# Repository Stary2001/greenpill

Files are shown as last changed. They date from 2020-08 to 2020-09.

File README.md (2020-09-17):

Greenpill
===
*Breadboard-able SAMD51 development board*

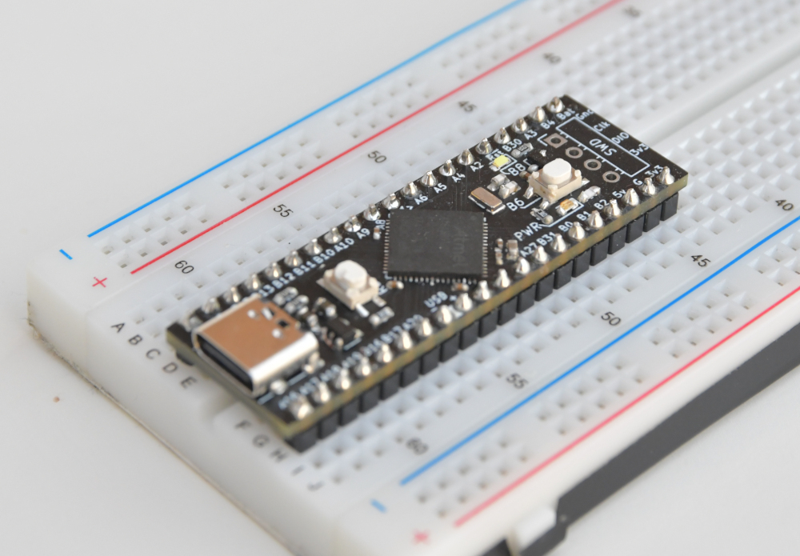
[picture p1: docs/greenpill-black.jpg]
Assembled PCB in a breadboard


Inspired by the popular low-cost "Bluepill" and "Blackpill" STM32 boards, Greenpill aims to maintain some compatibility with those designs while adding features from the SAMD5x platform. Greenpill is designed to be used with [CircuitPython], although a SAMD51 port of Arduino could also be used.

## Features
 - SAMD51J20A-M microcontroller
   - Arm Cortex-M4 @ 120 MHz
   - 8 USB endpoints &ndash; enough for CDC & MSC (for CircuitPython), and some extras (eg. AUDIO)
 - Reversible USB Type-C connector supporting USB 2.0 data rates
 - On-board user LED and button
 - External 32.768 kHz crystal oscillator for RTC + clock source.
 - Up to 13 PWM-capable pins usable **simultaneously**
 - SPI flash footprint on underside - no pin conflicts with broken out pins (uses **SERCOM2**).

Greenpill Schematic

## Flashing CircuitPython
1. **TODO: add UF2 bootloader instructions**
2. [Build CircuitPython][BuildCPy] from [the fork][CPyFork]. Use the `atsamd` port and `BOARD=greenpill`.
3. Enter the UF2 bootloader by double-tapping the RESET button on Greenpill
4. You should now have a removable storage device called `CPYBOOT`. Copy `PATHTOUF2` to the root directory of this device. Once it has finished copying, `CPYBOOT` will disappear and `GREENPILL` will appear. You have now installed CircuitPython.

## Pin assignment
Pins are numbered **counter-clockwise** starting at the top-left pin (to the left of the USB-C connector).

| Greenpill Pin | GPIO name  | Available SERCOMs* | Available PWM timers* | Comment |
|---|---|---|---|---|
| User LED | PB09 | - | TC4/WO[1] | |
| User Button | PB06 | - | - | Externally pulled up to 3v3 |
| VBat sense | PB03 | - | - | Connected to VBat via diode D3 |
| 1 | PA16 | SERCOM1/PAD[0]<br>SERCOM3/PAD[1] | TCC1/WO[0]<br>TCC0/WO[4] | |
| 2 | PA17 | SERCOM1/PAD[1]<br>SERCOM3/PAD[0] | TC2/WO[1]<br>TCC1/WO[1]<br>TCC0/WO[5] | |
| 3 | PA18 | SERCOM1/PAD[2]<br>SERCOM3/PAD[2] | TCC1/WO[2]<br>TCC0/WO[6] | |
| 4 | PA19 | SERCOM1/PAD[3]<br>SERCOM3/PAD[3] | TC3/WO[1]<br>TCC1/WO[3]<br>TCC0/WO[7] | |
| 5 | PB16 | SERCOM5/PAD[0] | TCC3/WO[0]<br>TCC0/WO[4] | |
| 6 | PB01 | SERCOM5/PAD[3] | TC7/WO[1] | |
| 7 | PB00 | SERCOM5/PAD[2] | - | |
| 8 | PA24 | | | USB D- |
| 9 | PA25 | | | USB D+ |
| 10 | PA20 | SERCOM5/PAD[2]<br>SERCOM3/PAD[2] | TCC1/WO[4]<br>TCC0/WO[0] - | |
| 11 | PB22 | SERCOM1/PAD[2]<br>SERCOM5/PAD[2] | | |
| 12 | PB23 | SERCOM1/PAD[3]<br>SERCOM5/PAD[3] | TC7/WO[1] | |
| 13 | PA27 | - | - | |
| 14 | PB31 | SERCOM5/PAD[0] | TC0/WO[1]<br>TCC4/WO[1]<br>TCC0/WO[7] | |
| 15 | PA22 | SERCOM3/PAD[0]<br>SERCOM5/PAD[1] | TCC1/WO[6]<br>TCC0/WO[2] | |
| 16 | PB17 | SERCOM5/PAD[1] | TC6/WO[1]<br>TCC3/WO[1]<br>TCC0/WO[5] | |
| 17 | PB02 | SERCOM5/PAD[0] | TCC2/WO[2] | |
| 18 | **5V** | | | |
| 19 | **Ground** | | | |
| 20 | **3.3V** | | | |
| 21 | VBat | | | |
| 22 | PB04 | - | - | |
| 23 | PA03 | - | - | |
| 24 | PB30 | SERCOM5/PAD[1] | TCC4/WO[0]<br>TCC0/WO[6] | |
| 25 | ¬Reset | | | |
| 26 | PA02 | - | - | |
| 27 | PA08 | SERCOM4/PAD[0] | - | |
| 28 | PA05 | SERCOM0/PAD[1] | TC0/WO[1] | |
| 29 | PA07 | SERCOM0/PAD[3] | TC1/WO[1] | |
| 30 | PA06 | SERCOM0/PAD[2] | - | |
| 31 | PA04 | SERCOM0/PAD[0] | - | |
| 32 | PA09 | SERCOM0/PAD[1] | TC0/WO[1]<br>TCC0/WO[1]<br>TCC1/WO[5] | |
| 33 | PA10 | SERCOM0/PAD[2] | TCC0/WO[2]<br>TCC1/WO[6] | |
| 34 | PB10 | SERCOM4/PAD[2] | TCC0/WO[4]<br>TCC1/WO[0] | |
| 35 | PB11 | SERCOM4/PAD[3] | TC5/WO[1]<br>TCC0/WO[5]<br>TCC1/WO[1] | |
| 36 | PB12 | SERCOM4/PAD[0] | TCC3/WO[0]<br>TCC0/WO[0] | |
| 37 | PB13 | SERCOM4/PAD[1] | TC4/WO[1]<br>TCC3/WO[1]<br>TCC0/WO[1] | |
| 38 | **3.3V** | | | |
| 39 | **Ground** | | | |
| 40 | **5V** | | | |

\* SERCOM2 and all TC*n*/WO[0] have been removed from this table. SERCOM2 is used by the SPI flash, and TC*n*/WO[0] timers are not usable for PWM output by CircuitPython. For a full reference of pin capability, see Table 6-1 in the [SAM D5x datasheet][samd5xdata]

## License
The contents of this repository, which include the Greenpill hardware, documentation, and design files, are released under the **Solderpad 2.1 license**. The recommended firmware for GreenPill (CircuitPython) is NOT part of this repository. Both [Adafruit/CircuitPython][CircuitPython] and the [fork][CPyFork] that provides Greenpill compatibility are released under the **MIT License** 

[CircuitPython]: https://github.com/Adafruit/CircuitPython "Adafruit/CircuitPython on GitHub"
[CPyFork]: https://github.com/Stary2001/circuitpython/tree/greenpill "Branch 'greenpill' from Stary2001/CircuitPython on GitHub; forked from Adafruit"
[BuildCPy]: https://learn.adafruit.com/building-circuitpython?view=all "Building CircuitPython | Adafruit Learning System"
[samd5xdata]: https://ww1.microchip.com/downloads/en/DeviceDoc/SAM_D5xE5x_Family_Data_Sheet_DS60001507F.pdf "SAM D5x/E5x Family Data Sheet | Microchip (PDF)"

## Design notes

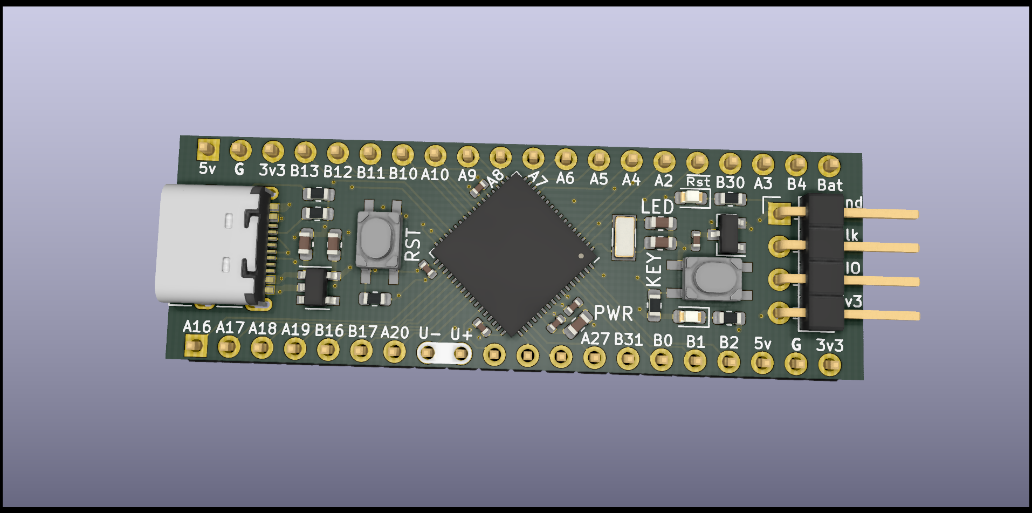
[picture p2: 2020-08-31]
1.0/greenpill.png

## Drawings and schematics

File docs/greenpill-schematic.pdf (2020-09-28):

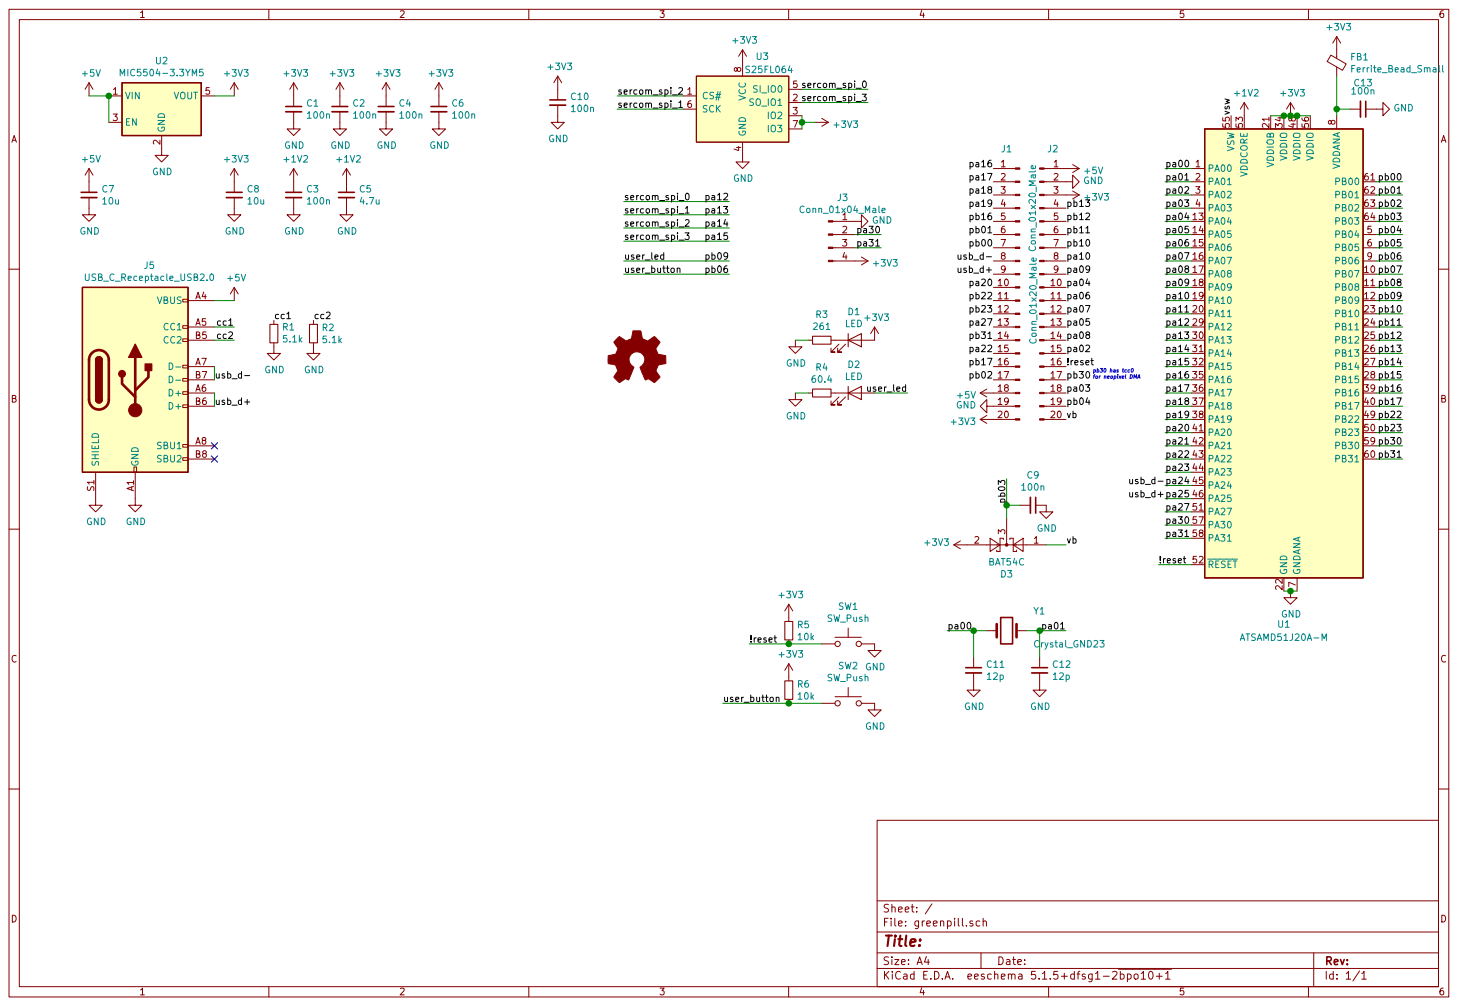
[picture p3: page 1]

File: greenpill.sch Sheet: /
Id: 1/1 Title:

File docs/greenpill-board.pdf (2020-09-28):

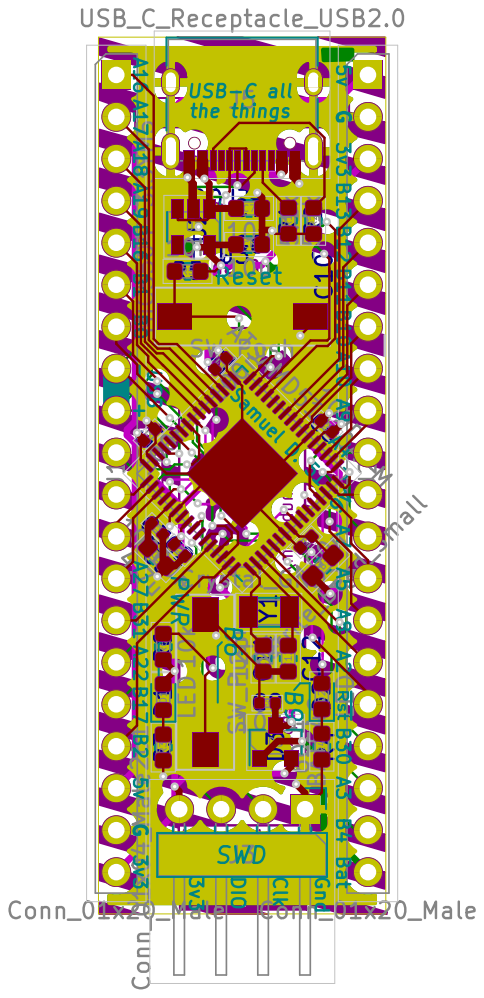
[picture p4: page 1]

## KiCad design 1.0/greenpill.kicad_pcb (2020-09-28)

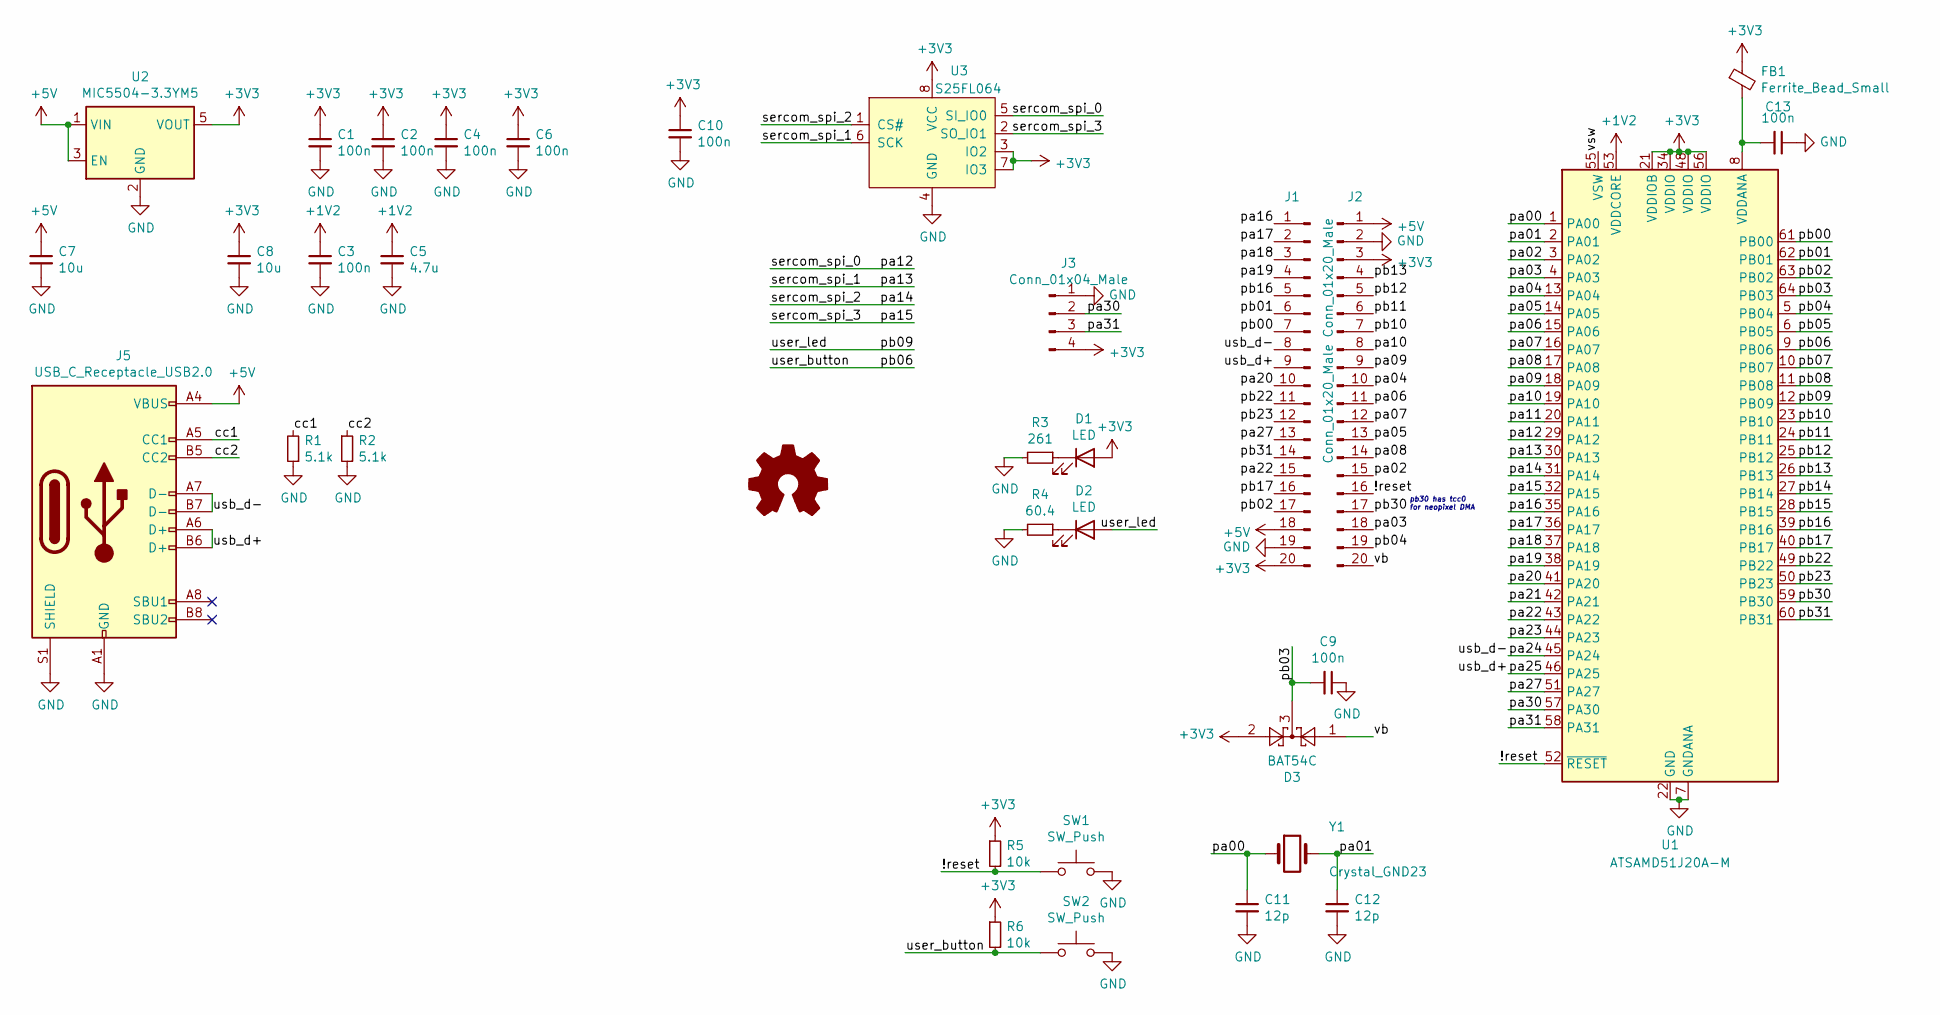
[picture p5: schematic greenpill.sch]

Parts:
C1, C2, C3, C4, C6, C9, C10: 100n; C_0402_1005Metric; MPN GRM155R61A104KA01J
C5: 4.7u; C_0603_1608Metric; MPN CL10A475KQ8NNNC
C7, C8: 10u; C_0603_1608Metric; MPN GRM188R61A106KE69J
C11, C12: 12p; C_0603_1608Metric; MPN C0603C120J5GACTU
C13: 100n; C_0402_1005Metric
D1: LED; LED_0603_1608Metric; MPN 150060RS75000
D2: LED; LED_0603_1608Metric; MPN 150060BS75000
D3: BAT54C; SOT-23; MPN BAT54C,215
FB1: Ferrite_Bead_Small; R_0603_1608Metric_Pad1.05x0.95mm_HandSolder
J1, J2: Conn_01x20_Male; PinHeader_1x20_P2.54mm_Vertical
J3: Conn_01x04_Male; PinHeader_1x04_P2.54mm_Horizontal
J5: USB_C_Receptacle_USB2.0; USB_C_Receptacle_XKB_U262-16XN-4BVC11; MPN lmao aliexpress
LOGO1: Logo_Open_Hardware_Small; OSHW-Symbol_4x4.5mm_SilkScreen
R1, R2: 5.1k; R_0603_1608Metric; MPN RC0603FR-075K1L
R3: 261; R_0603_1608Metric; MPN P261HCT-ND
R4: 60.4; R_0603_1608Metric; MPN RC0603FR-0760R4L
R5, R6: 10k; R_0603_1608Metric; MPN RC0603FR-0710KL
SW1, SW2: SW_Push; PTS636; MPN PTS815 SJM 250 SMTR LFS
U1: ATSAMD51J20A-M; QFN-64-1EP_9x9mm_P0.5mm_EP4.7x4.7mm; MPN ATSAMD51J20A-MU
U2: MIC5504-3.3YM5; SOT-23-5; MPN MIC5504-3.3YM5-TR
U3: S25FL064; SOIC-8_5.23x5.23mm_P1.27mm; MPN S25FL064LABMFN010
Y1: Crystal_GND23; Crystal_SMD_3215-2Pin_3.2x1.5mm; MPN FC-135 32.7680KA-A5

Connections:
+1V2: C3.1, C5.1, U1.53 (VDDCORE)
+3V3: C1.1, C2.1, C4.1, C6.1, C8.1, C10.1, D1.2 (A), D3.2, FB1.1, J1.20, J2.3, J3.4, R5.1, R6.1, U1.21 (VDDIOB), U1.34 (VDDIO), U1.48 (VDDIO), U1.56 (VDDIO), U2.5 (VOUT), U3.3 (IO2), U3.7 (IO3), U3.8 (VCC)
+5V: C7.1, J1.18, J2.1, J5.A4 (VBUS), J5.A9 (VBUS), J5.B4 (VBUS), J5.B9 (VBUS), U2.1 (VIN), U2.3 (EN)
/!reset: J2.16, R5.2, SW1.1, U1.52 (~RESET)
/cc1: J5.A5 (CC1), R1.2
/cc2: J5.B5 (CC2), R2.1
/pa00: C11.1, U1.1 (PA00), Y1.1
/pa01: C12.1, U1.2 (PA01), Y1.2
/pa02: J2.15, U1.3 (PA02)
/pa03: J2.18, U1.4 (PA03)
/pa04: J2.10, U1.13 (PA04)
/pa05: J2.13, U1.14 (PA05)
/pa06: J2.11, U1.15 (PA06)
/pa07: J2.12, U1.16 (PA07)
/pa08: J2.14, U1.17 (PA08)
/pa09: J2.9, U1.18 (PA09)
/pa10: J2.8, U1.19 (PA10)
/pa11: U1.20 (PA11)
/pa12: U1.29 (PA12), U3.5 (SI_IO0)
/pa13: U1.30 (PA13), U3.6 (SCK)
/pa14: U1.31 (PA14), U3.1 (CS#)
/pa15: U1.32 (PA15), U3.2 (SO_IO1)
/pa16: J1.1, U1.35 (PA16)
/pa17: J1.2, U1.36 (PA17)
/pa18: J1.3, U1.37 (PA18)
/pa19: J1.4, U1.38 (PA19)
/pa20: J1.10, U1.41 (PA20)
/pa21: U1.42 (PA21)
/pa22: J1.15, U1.43 (PA22)
/pa23: U1.44 (PA23)
/pa24: J1.8, J5.A7 (D-), J5.B7 (D-), U1.45 (PA24)
/pa25: J1.9, J5.A6 (D+), J5.B6 (D+), U1.46 (PA25)
/pa27: J1.13, U1.51 (PA27)
/pa30: J3.2, U1.57 (PA30)
/pa31: J3.3, U1.58 (PA31)
/pb00: J1.7, U1.61 (PB00)
/pb01: J1.6, U1.62 (PB01)
/pb02: J1.17, U1.63 (PB02)
/pb03: C9.2, D3.3, U1.64 (PB03)
/pb04: J2.19, U1.5 (PB04)
/pb05: U1.6 (PB05)
/pb06: R6.2, SW2.1, U1.9 (PB06)
/pb07: U1.10 (PB07)
/pb08: U1.11 (PB08)
/pb09: D2.2 (A), U1.12 (PB09)
/pb10: J2.7, U1.23 (PB10)
/pb11: J2.6, U1.24 (PB11)
/pb12: J2.5, U1.25 (PB12)
/pb13: J2.4, U1.26 (PB13)
/pb14: U1.27 (PB14)
/pb15: U1.28 (PB15)
/pb16: J1.5, U1.39 (PB16)
/pb17: J1.16, U1.40 (PB17)
/pb22: J1.11, U1.49 (PB22)
/pb23: J1.12, U1.50 (PB23)
/pb30: J2.17, U1.59 (PB30)
/pb31: J1.14, U1.60 (PB31)
/vb: D3.1, J2.20
/vsw: U1.55 (VSW)
GND: C1.2, C2.2, C3.2, C4.2, C5.2, C6.2, C7.2, C8.2, C9.1, C10.2, C11.2, C12.2, C13.1, J1.19, J2.2, J3.1, J5.A1 (GND), J5.A12 (GND), J5.B1 (GND), J5.B12 (GND), J5.S1 (SHIELD), R1.1, R2.2, R3.2, R4.2, SW1.2, SW2.2, U1.7 (GNDANA), U1.22 (GND), U1.33 (GND), U1.47 (GND), U1.54 (GND), U1.65 (GND), U2.2 (GND), U3.4 (GND)
unnamed: C13.2, FB1.2, U1.8 (VDDANA)
unnamed: D1.1 (K), R3.1
unnamed: D2.1 (K), R4.1

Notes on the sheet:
pb30 has tcc0 for neopixel DMA

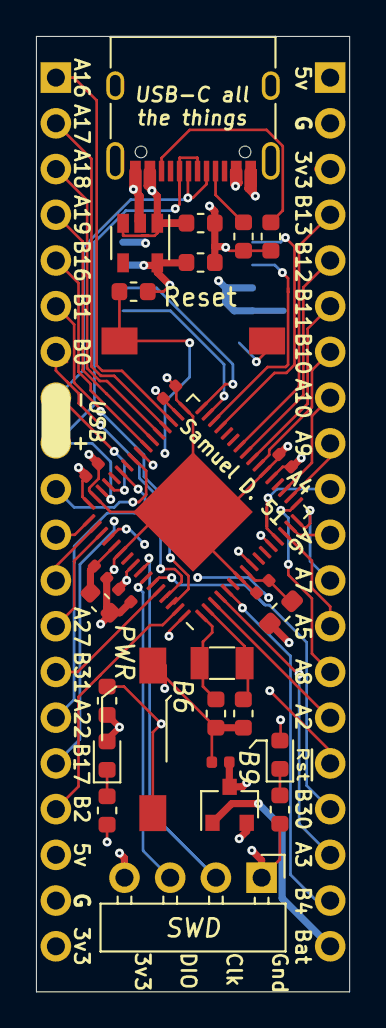
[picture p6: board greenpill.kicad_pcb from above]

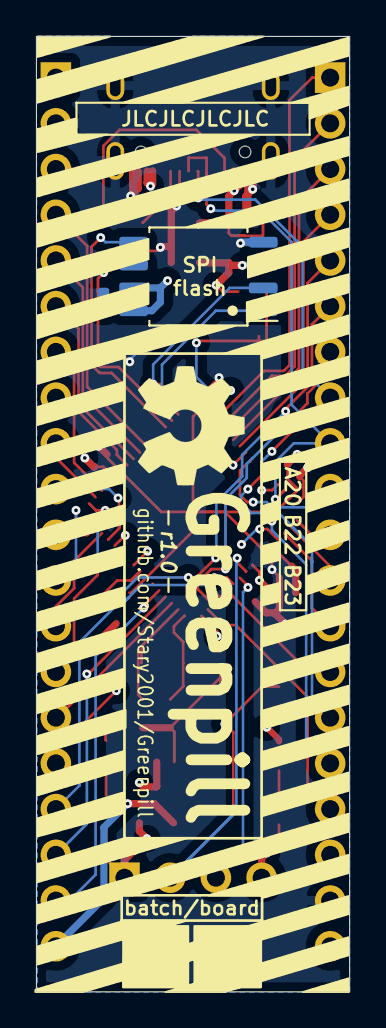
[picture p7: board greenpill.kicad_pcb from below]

Board: 4 copper layers, 17.4 x 53.1 mm, 33 parts (2 on the bottom side), 54 nets.

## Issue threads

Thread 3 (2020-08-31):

Write documentation

LukeMoll, 2020-08-31:
Including
 - [ ] Pin mapping
 - [ ] Instructions on how to flash CircuitPython

(Please add any other documentation sections here)

LukeMoll, 2020-09-13:
CircuitPython instructions are done apart from installing UF2. This is waiting on @Stary2001 to make a release of [uf2-samdx1][https://github.com/Stary2001/uf2-samdx1/tree/greenpill], which is in turn waiting on USB VID/PID codes for GreenPill.

LukeMoll, 2020-09-16:
Add "good enough" instructions on installing UF2, for the purposes of OSHA certification. When GreenPill is submitted to CircuitPython and we have VID/PID codes, then the instructions can be updated to use a released binary of uf2-samdx1.

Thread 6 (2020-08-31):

Fix pinmap

LukeMoll, 2020-08-31:
- [x] Choose new pin assignments so that each pin connected to an LED on [Textier](https://github.com/lukemoll/textier) has a timer that CircuitPython can use for PWM to itself.
 - [x] Re-route board
 - [x] Update silkscreen labels

LukeMoll, 2020-09-13:
The User LED on PB08 only has TC4/WO[0] available, which means that CircuitPython cannot use it as a PWM output. This must be fixed before #6 is closed.

LukeMoll, 2020-09-13:
with dd3e70a, User LED is now on PB09, using TC4/WO[1].

Closed 2020-09-16.

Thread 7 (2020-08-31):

Fix silkscreen

LukeMoll, 2020-08-31:
- [ ] Open Hardware gear logo doesn't print on final boards
 - [ ] **When certified** put OSHW certification logo on boards

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

LukeMoll, 2020-09-13:
See also #10

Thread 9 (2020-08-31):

Fix text in copper layer

Stary2001, 2020-08-31:
Text in copper is a cool effect, but seemed to be inconsistent (it worked fine in black soldermask, but not in green). Maybe tweak the width/size a bit to make it consistent.

Closed 2020-09-16.

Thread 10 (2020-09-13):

Add silkscreen box for board/batch #

LukeMoll, 2020-09-13:
White box on underside to mark batch and board number (useful for cataloguing which boards have faults)

LukeMoll, 2020-09-16:
This might fit neatly below the SWD header on the underside of the board

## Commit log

2020-06-29 Trimmed board, added pinout silkscreen
    [greenpill.kicad_pcb]
2020-06-29 PINOUT CHANGE, rerouted and updated silk.s
    Swapped left pins 13 and 16 (formerly A21 & A27 respectively) so PWM output on A21 can be used for Textier LED4:G. A27 now on pin L13 is used for key matrix scanning and so doesn't require PWM
    Rerouted only affected traces
    Swapped silkscreen labels
    [greenpill.kicad_pcb, greenpill.sch]
2020-06-29 a bit of tweaking
    [greenpill.kicad_pcb, greenpill.sch]
2020-07-05 Switched to QFN-64 package, reassigned pins. Trimmed Edge.Cuts
    Still TODO:
    - Redo silkscreen
    - Move passives near MCU to optimal position (1v2 caps especially)
    [greenpill.kicad_pcb, greenpill.sch]
2020-07-06 Routed trivial IOs
    [greenpill.kicad_pcb]
2020-07-11 Updated silkscreen
    [greenpill.kicad_pcb]
2020-07-11 poke layout a bit
    [greenpill.kicad_pcb]
2020-07-11 Added 3D models
    [greenpill.kicad_pcb]
2020-07-11 Added * f u n k y * back silkscreen, some front silkscreen tweaks
    [greenpill.kicad_pcb]
2020-07-11 swapped button and led to non broken out pins
    [greenpill.kicad_pcb, greenpill.sch]
2020-07-24 add mpns
    [greenpill.kicad_pcb, greenpill.sch]
2020-07-25 revert meme
    [greenpill.kicad_pcb]
2020-09-03 change pinout to hopefully have full timer coverage
    [greenpill.kicad_pcb, greenpill.sch]
2020-09-13 Updated index.md
    - User LED doesn't have PWM
    - Added SPI flash note
    - Added building CPy details
    - Fixed link to forked CPy
2020-09-13 Add GitHub Actions CI for generating schematics (closes #8) (#11)
    Seems good enough
    * Added github actions for KiPlot
    * Whoops moved config.kiplot.yaml to the right dir
    * Moved `ls` up
    * Changed to consistent lower case
    * Change to only using the first page
    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
2020-09-13 Added solderpad license (closes #5)
2020-09-13 Added note about SPI flash SERCOM 2
2020-09-13 Moved User LED from PB08 to PB09
    - Updated schematic
    - Rerouted trace
    - Updated silkscreen
    [greenpill.kicad_pcb, greenpill.sch]
2020-09-16 Fix silkscreen for new pinout, add PTS636 3D model.
    [greenpill.kicad_pcb, greenpill.sch]
2020-09-16 move silkscreen around on the bottom, add gear logo, adjust copper text
    [greenpill.kicad_pcb, greenpill.sch]
2020-09-17 oops, remove 2nd schematic
2020-09-19 shift around basically all the silkscreen on the back
    [greenpill.kicad_pcb]
2020-09-27 Moved board/batch number boxes on B.SilkS
    [greenpill.kicad_pcb]
2020-09-28 Added r1.0 text
    [greenpill.kicad_pcb]
